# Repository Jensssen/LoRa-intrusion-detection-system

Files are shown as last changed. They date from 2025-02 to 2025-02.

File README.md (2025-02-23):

# Alarm system

This project contains the code for an alarm system that can be used to monitor windows or doors in our house. 
The system is based on a Raspberry Pi 4 Model B and uses buttons to detect if a window or door is opened or closed.
In my case, I am using the system to detect intruders, in our cellar room. In case of a detection, a notification is sent
to my phone. In addition, an alarm sound is played in order to scare the intruder away.
In 2024, we had 4 break-ins/beak-in attempts. I hope that with this system will be able to prevent future break-ins. 

## System design
The system is split into a transmitter, a receiver and a server backend. Below you can see the system design of the transmitter.
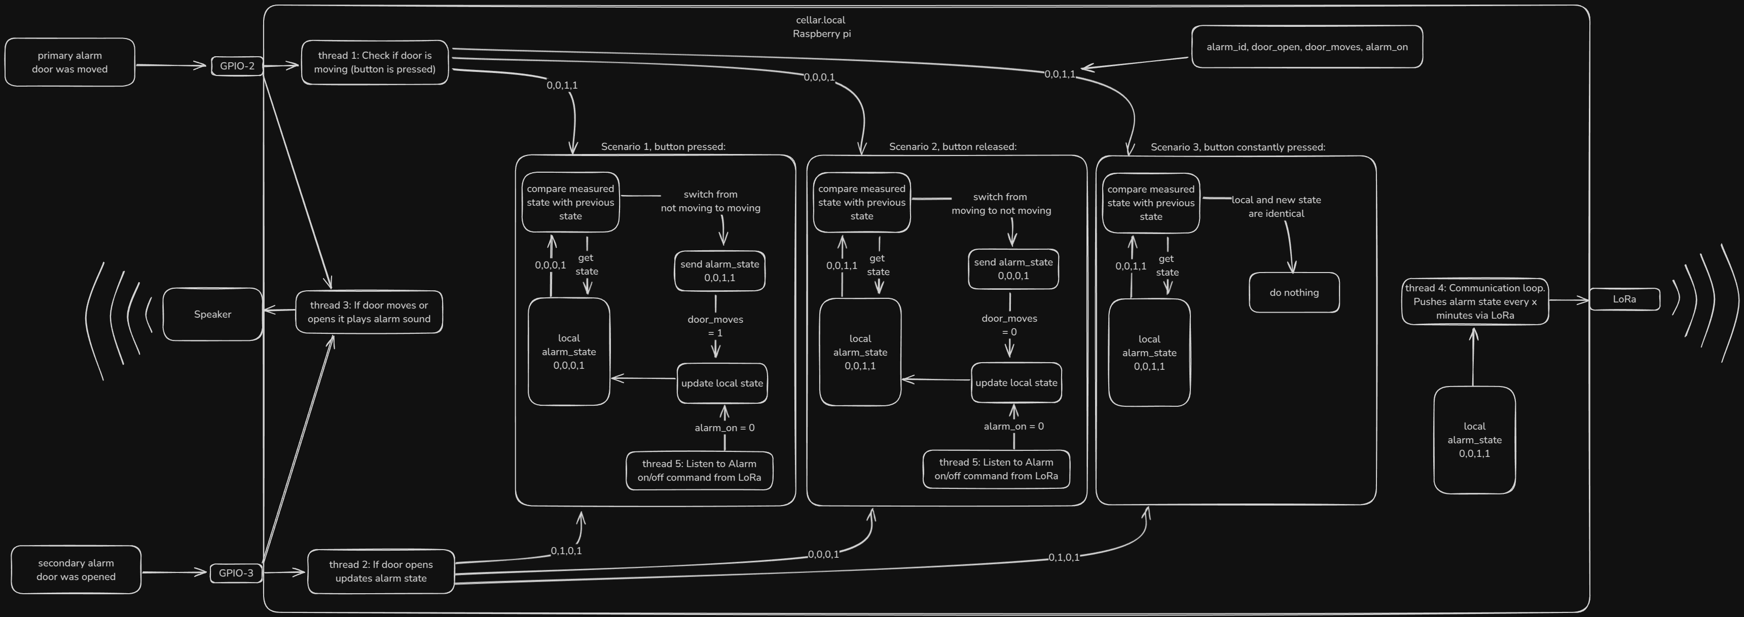
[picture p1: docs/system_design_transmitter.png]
System Design Transmitter

There are multiple threads running on the transmitter system. Two are constantly observing the buttons, which are attached to the 
door in our cellar. A third thread is observing the local alarm state. If the alarm is triggered, the alarm sound is played.
A forth thread is sending the alarm state via LoRa to my second Raspberry Pi every 15 minutes. This thread is also listening 
for ON/OFF events. Therefore, it is a bidirectional communication, however in 99% of the time, the transmitter is sending. 

Below you can see the system design of the receiver module and the server backend.
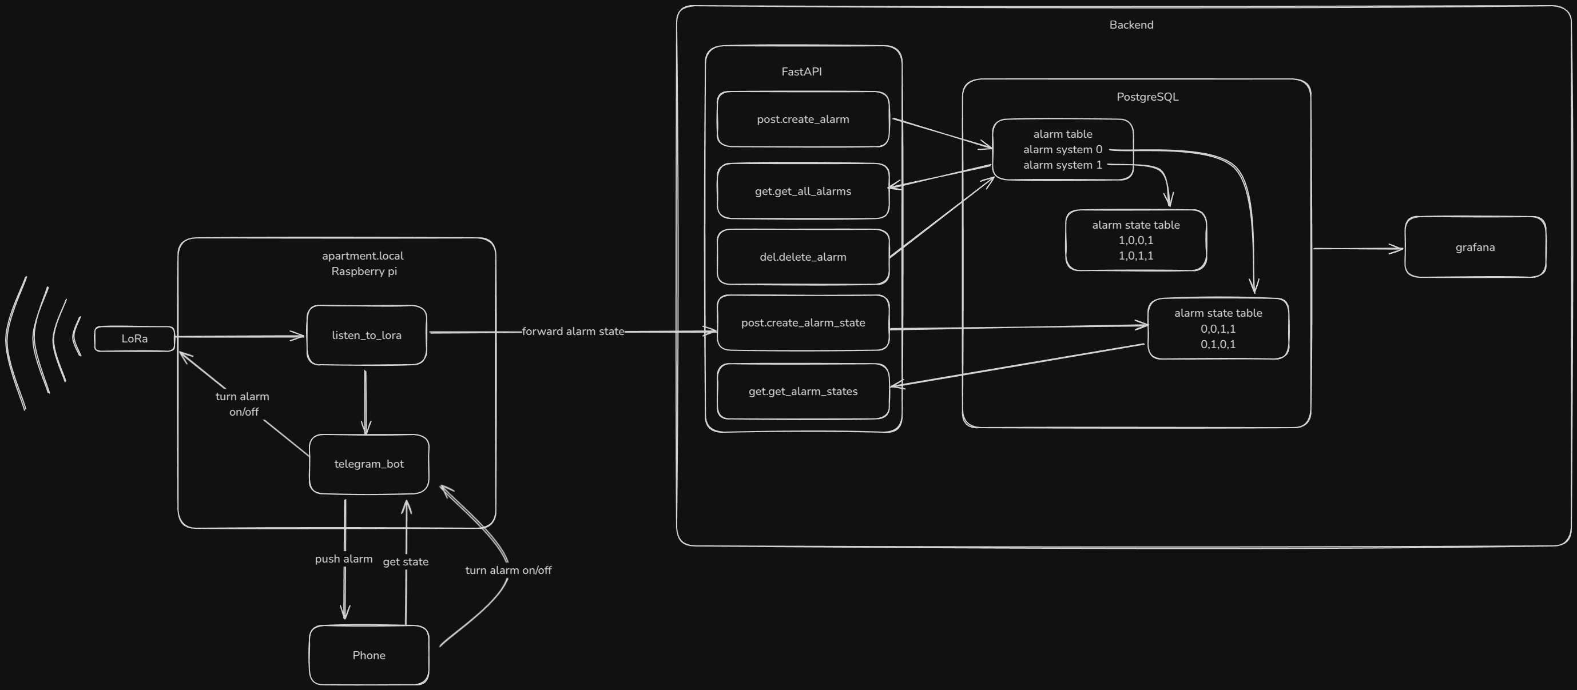
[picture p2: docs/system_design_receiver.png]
System Design Receiver


The receiver module is simply listening for incoming LoRa messages which are then forwarded to the backend server. 
The backend server has a FastAPI REST API, which is used to store the alarm state in a postgres database. In addition,
a Grafana dashboard is used to visualize the alarm state.
The receiver module is also running the Telegram bot, which is also used to forward incoming alarm messages to my phone.
In addition, the Telegram bot interface can also be used to turn the alarm on or off.

## Raspberry Pi 4 Model B setup

### OS setup

1. Install the rpi-imager `sudo apt install rpi-imager`
2. Go to settings and:
   1. Configure a hostname
   2. Enable ssh and allow public key usage only
   3. Paste a public key
   4. Configure wireless LAN
   5. Set your timezone
3. Finally, select your SD and flash the SD card with an operating system, such as Ubuntu Server 24.04 LTS.

### Setup ssh
1. Go to `~/.ssh` and add the following configuration entry:
    ```
    Host <your selected host name from OS setup>
         HostName <the IP address of the Raspberry Pi> <- You can get the IP by logging into your router
         User <username from OS step>
         Port 22
         IdentityFile ~/.ssh/your_private_key
    ```
2. Now run ssh <your selected host name> and enter your ssh key password
3. You should be logged into your Raspberry Pi now
4. If you get an error, our your connection does not work, mount the SD card on your system, add an empty file named `ssh` to the boot partition, and try again.
5. If it still does not work, edit the file `/etc/sshd_config` and set `PasswordAuthentication no`, `Port 22` and `PubkeyAuthentication yes`, reboot the Raspberry PI and try again.

### Enable serial port

1. Run `sudo apt install raspi-config` and run `sudo raspi-config`
2. Navigate to `Interfacing Options` -> `Serial Port` and enable the serial port. Do not make your login shell accessible over serial!

### Setup Python

1. run `sudo apt-get update && sudo apt-get upgrade`
2. run `sudo apt install python3-pip` to install the python package manager
3. run `sudo apt install python3-rpi-lgpio` to install the GPIO library

# Demo
[Link to Grafana Dashboard](https://grafana.memomate.me/public-dashboards/ea42cdf5d8614cfd9fa721148ae74071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)

[Link to YouTube video](https://youtu.be/yvn0n6daogU)

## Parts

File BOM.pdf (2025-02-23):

Product | Amount | Price | Sum
Raspberry pi B 1GB Ram (https://www.berrybase.de/raspberry-pi-4-computer-modell-b-1gb-ram) | 2 | 40.5 | 81
SanDisk micro SD (https://www.amazon.de/Adapter-High-Speed-Speicherkarte-Mobiltelefon-TF162/dp/B0CYSMZ8Z6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) | 2 | 5.5 | 11
SX1262 LoRa Hat, 868 MHz (https://www.berrybase.de/sx1262-lora-hat-fuer-raspberry-pi-868-mhz-frequenz-band?gad_source=1) | 2 | 24.9 | 49.8

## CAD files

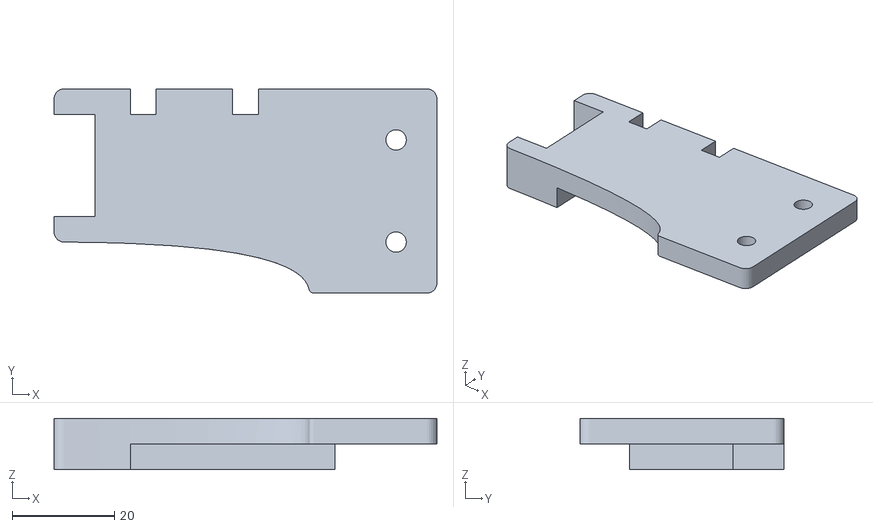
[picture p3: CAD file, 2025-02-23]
CAD_designs/button_mount_v5-Body.stl
75.0 x 40.0 x 10.0

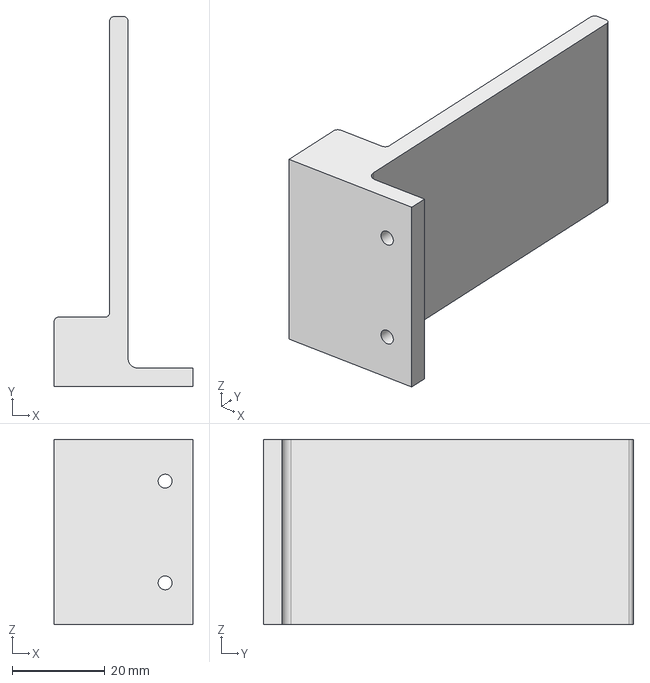
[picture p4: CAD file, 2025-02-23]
CAD_designs/button_counterpart_v1.FCStd
30.0 x 80.0 x 40.0 mm

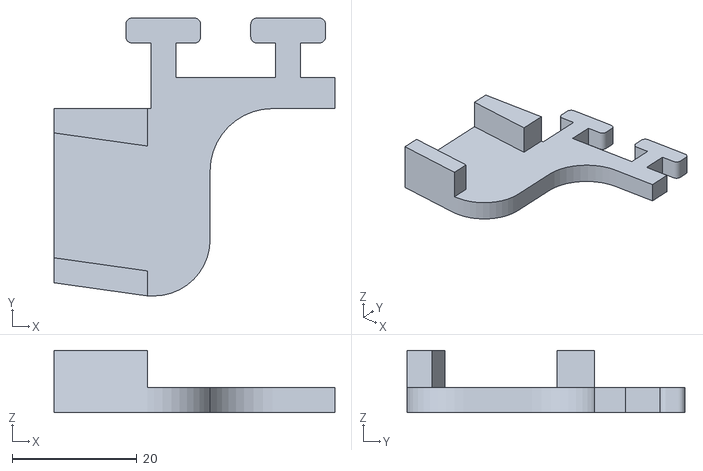
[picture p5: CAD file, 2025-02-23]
CAD_designs/door_open_button_mount_v2-Body.stl
45.0 x 44.5 x 10.0

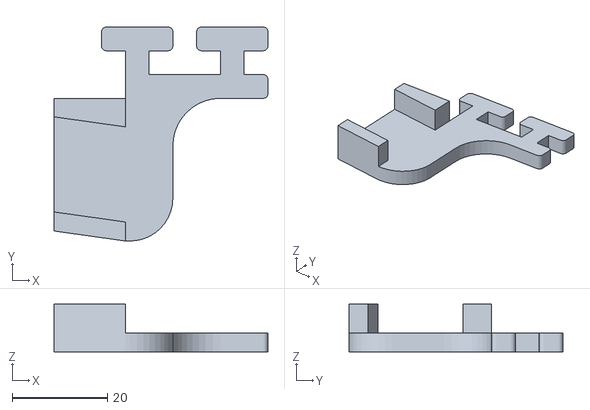
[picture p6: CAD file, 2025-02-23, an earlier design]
CAD_designs/door_open_button_mount_v1-Body.stl
45.0 x 45.0 x 10.0

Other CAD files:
CAD_designs/button_mount_v6.FCStd
CAD_designs/button_mount_v5.FCStd
CAD_designs/button_counterpart_v1-Body.stl
CAD_designs/door_open_button_mount_v2.FCStd
CAD_designs/button_mount_v6-Body.stl
CAD_designs/door_open_button_mount_v1.FCStd

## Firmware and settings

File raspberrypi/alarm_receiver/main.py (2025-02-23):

import os
import sys

import serial
import telegram.ext as tg_ext
from dotenv import load_dotenv
from loguru import logger
from telegram import Update
from telegram.ext import MessageHandler, filters, ContextTypes
import re

from alarm_handler import AlarmHandler

load_dotenv()
logger.remove()
logger.add(sys.stdout, level=os.environ['LOGLEVEL'].upper())

TELEGRAM_TOKEN = os.environ['TELEGRAM_BOT_KEY']
TELEGRAM_CHAT_ID = os.environ['TELEGRAM_CHAT_ID']
ALARM_API_KEY = os.environ['ALARM_API_KEY']
if TELEGRAM_TOKEN is None:
    logger.info("TELEGRAM_TOKEN env var not set")
    raise ValueError("No Telegram token provided")

lora = serial.Serial(port='/dev/ttyS0', baudrate=9600, parity=serial.PARITY_NONE, stopbits=serial.STOPBITS_ONE,
                     bytesize=serial.EIGHTBITS, timeout=1)

alarm_handler = AlarmHandler(ALARM_API_KEY)
ALARMS = ["5f525bd9-0a81-4cba-9fa5-f3fce4937f41"]
ALARM_NAMES = ["Cellar"]


def is_valid_binary_pattern(s: str) -> bool:
    """Check if the given string is a valid alarm state pattern."""
    pattern = r"^(0|[1-9]\d*)(,(0|1)){3}(,(0|[1-9]\d*)(,(0|1)){3})*$"
    return bool(re.fullmatch(pattern, s))


async def listen_to_lora(context: tg_ext.CallbackContext) -> None:
    """Listen to incoming LoRa messages and send the alarm state to the API."""
    data_read = lora.readline().decode('utf-8').strip()
    if data_read != "":
        if is_valid_binary_pattern(data_read):
            alarm_id, is_open, is_moving, is_on = data_read.split(",")[0:4]
            alarm = {
                "alarm_id": ALARMS[int(alarm_id)],
                "is_open": bool(int(is_open)),
                "wiggles": bool(int(is_moving)),
                "alarm_on": bool(int(is_on)),
            }
            logger.debug(f"Sending Data to API: {alarm}")
            alarm_handler.send_alarm_state(alarm)

            if bool(int(is_open)):
                message = f"{ALARM_NAMES[int(alarm_id)]} door is open!"
                await context.bot.send_message(TELEGRAM_CHAT_ID, message)
            if bool(int(is_moving)):
                message = f"{ALARM_NAMES[int(alarm_id)]} door is moving!"
                await context.bot.send_message(TELEGRAM_CHAT_ID, message)


def send_lora_message(message: str) -> None:
    """Send LoRa message."""
    lora.write(bytes(message, 'utf-8'))
    logger.debug(f"LoRa message was sent: {message}")


async def handle_message(update: Update, context: ContextTypes.DEFAULT_TYPE) -> None:
    """Handle incoming telegram messages. The message is checked for on/off commands."""
    if str(update.message.chat.first_name) == os.environ['TELEGRAM_USER_NAME']:
        if update.message.text.lower()[0:3] == "on:":
            message = update.message.text.lower()
            command, alarm_id = message.split(":")
            send_lora_message(update.message.text.lower())
            await update.message.reply_text(f"Alarm with ID {alarm_id} has been turned ON")
        elif update.message.text.lower()[0:4] == "off:":
            message = update.message.text.lower()
            command, alarm_id = message.split(":")
            send_lora_message(update.message.text.lower())
            await update.message.reply_text(f"Alarm with ID {alarm_id} has been turned OFF")
        else:
            await update.message.reply_text(f"Your Provided command: {update.message.text} is not supported. \n"
                                            f"Please use one of the following commands: \n"
                                            f"on:<alarm_idx>, off:<alarm_idx>")


if __name__ == '__main__':
    app = tg_ext.ApplicationBuilder().token(TELEGRAM_TOKEN).build()
    app.add_handler(MessageHandler(filters.TEXT, handle_message))

    job_queue = app.job_queue
    job_queue.run_repeating(listen_to_lora, interval=5, first=1)
    app.run_polling()

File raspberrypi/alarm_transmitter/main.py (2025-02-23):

import os
import threading
import time
from datetime import datetime

import pygame
import serial
from gpiozero import Button, LED

from alarm_state import AlarmState

wiggle_button = Button(2)
door_button = Button(3)
alarm_on_off_led = LED(17)
STATUS_FREQUENCY = 15
pygame.mixer.init()
pygame.mixer.music.load(os.path.join(os.path.dirname(os.path.abspath(__file__)), "red-alert_nuclear_buzzer-99741.mp3"))
lora = serial.Serial(port='/dev/ttyS0', baudrate=9600, parity=serial.PARITY_NONE, stopbits=serial.STOPBITS_ONE,
                     bytesize=serial.EIGHTBITS, timeout=1)

door = AlarmState(alarm_id=0, is_open=0, is_moving=0, alarm_on=1)
alarm_on_off_led.on()


def alarm_sound_system() -> None:
    """Play alarm sound."""
    while True:
        if wiggle_button.is_pressed or door_button.is_pressed:
            if door.alarm_on:
                pygame.mixer.music.play()
                while pygame.mixer.music.get_busy():
                    pass
                print("Alarm sound played!")
        time.sleep(0.1)


def update_door_moving_state(door_is_moving: int) -> None:
    """
    Compare the new with the current door moving alarm state and update the if necessary.
    It also sends the updated alarm state via LoRa, but only on a state change!
    """
    if door_is_moving == 1:
        if door.is_moving != door_is_moving:
            # Door is moving and was not moving before
            door.door_is_moving()
            send_message(str(door))
    else:
        if door.is_moving != door_is_moving:
            # Door is not moving anymore
            door.door_is_not_moving()
            send_message(str(door))


def update_door_is_open_state(door_is_open: int) -> None:
    """
    Compare the new with the current door open alarm state and update the if necessary.
    It also sends the updated alarm state via LoRa, but only on a state change!
    """
    if door_is_open == 1:
        if door.is_open != door_is_open:
            # Door is now open and was not open before
            door.door_is_open()
            send_message(str(door))
    else:
        if door.is_open != door_is_open:
            # Door is not open anymore
            door.door_is_not_open()
            send_message(str(door))


def door_moving_detection() -> None:
    """Checks constantly if the door is moving."""
    while True:
        if wiggle_button.is_pressed:
            update_door_moving_state(1)
        else:
            update_door_moving_state(0)
        time.sleep(0.1)


def door_open_detection() -> None:
    """Checks constantly if the door is open."""
    while True:
        if door_button.is_pressed:
            update_door_is_open_state(1)
        else:
            update_door_is_open_state(0)
        time.sleep(0.1)


def send_message(message: str) -> None:
    """Send a message via LoRa."""
    print(f"Sending: {message}")
    lora.write(bytes(str(message), 'utf-8'))
    time.sleep(5)


def listen_to_lora() -> None:
    """Constantly listen to LoRa for incoming messages. The message is checked for on/off commands."""
    while True:
        data_read = lora.readline().decode('utf-8').strip()
        if "on:" in data_read.lower():
            alarm_id = data_read.split(":")[-1]
            if int(alarm_id) == door.alarm_id:
                door.turn_alarm_on()
                print("Turned alarm on!")
                send_message(str(door))
                alarm_on_off_led.on()

        elif "off:" in data_read.lower():
            alarm_id = data_read.split(":")[-1]
            if int(alarm_id) == door.alarm_id:
                door.turn_alarm_off()
                print("Turned alarm off!")
                alarm_on_off_led.off()
                send_message(str(door))
        elif data_read != "":
            print(data_read)
        time.sleep(0.1)


def communication_loop() -> None:
    """Send the current alarm state every STATUS_FREQUENCY minutes."""
    last_minute = datetime.now().minute

    while True:
        current_minute = datetime.now().minute
        if current_minute % STATUS_FREQUENCY == 0 and current_minute != last_minute:
            print(f"Send alarm state because timer reached minute {STATUS_FREQUENCY}")
            send_message(str(door))
            last_minute = current_minute
        time.sleep(1)


if __name__ == '__main__':
    print("Start alarm system ...")

    t1 = threading.Thread(target=door_moving_detection)
    t2 = threading.Thread(target=door_open_detection)
    t3 = threading.Thread(target=communication_loop)
    t4 = threading.Thread(target=listen_to_lora)
    t5 = threading.Thread(target=alarm_sound_system)

    t1.start()
    t2.start()
    t3.start()
    t4.start()
    t5.start()

    t1.join()
    t2.join()
    t3.join()
    t4.join()
    t5.join()

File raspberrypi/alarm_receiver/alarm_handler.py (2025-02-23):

import os
import sys

import requests
from dotenv import load_dotenv
from loguru import logger

load_dotenv()
logger.remove()
logger.add(sys.stdout, level=os.environ['LOGLEVEL'].upper())


class AlarmHandler:

    def __init__(self, token: str) -> None:
        self.headers = {"Authorization": f"Bearer {token}", "Content-Type": "application/json"}
        self.url = "https://house-alarm.memomate.me/app/v1/"

    def send_alarm_state(self, data: dict) -> None:
        """
        Send the current alarm state to the alarm API.

        Args:
            data: Dictionary holding the create_alarm_state (see docs)
        """
        try:
            response = requests.post(self.url + "create_alarm_state", json=data, headers=self.headers, timeout=10)
            response.raise_for_status()
            logger.info(f"Response Status Code: {response.status_code}")

            try:
                response_json = response.json()
                logger.debug(f"Response JSON: {response_json}")
            except ValueError:
                logger.error(f"Response is not in JSON format: {response.text}")

        except requests.exceptions.Timeout:
            logger.error("Request timed out. The server may be unreachable.")
        except requests.exceptions.ConnectionError:
            logger.error("Failed to connect to the server. Check if the server is running.")
        except requests.exceptions.HTTPError as err:
            logger.error(f"HTTP error occurred: {err}")
        except requests.exceptions.RequestException as err:
            logger.error(f"An error occurred: {err}")

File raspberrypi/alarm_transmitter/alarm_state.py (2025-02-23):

from dataclasses import dataclass


@dataclass
class AlarmState:
    alarm_id: int = 0
    is_open: int = 0
    is_moving: int = 0
    alarm_on: int = 1

    def __str__(self) -> str:
        return f"{self.alarm_id},{self.is_open},{self.is_moving},{self.alarm_on}"

    def __repr__(self) -> str:
        return f"{self.alarm_id},{self.is_open},{self.is_moving},{self.alarm_on}"

    def door_is_moving(self) -> None:
        self.is_moving = 1

    def door_is_not_moving(self) -> None:
        self.is_moving = 0

    def door_is_open(self) -> None:
        self.is_open = 1

    def door_is_not_open(self) -> None:
        self.is_open = 0

    def turn_alarm_on(self) -> None:
        self.alarm_on = 1

    def turn_alarm_off(self) -> None:
        self.alarm_on = 0

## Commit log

2025-02-23 fix style and types
    [main.py]
2025-02-23 add cad files
    [button_counterpart_v1-Body.stl, button_counterpart_v1.FCStd, button_mount_v5-Body.stl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]
2025-02-23 put alarm sound system in separate thread
2025-02-23 add alarm on off led
2025-02-23 add bom
